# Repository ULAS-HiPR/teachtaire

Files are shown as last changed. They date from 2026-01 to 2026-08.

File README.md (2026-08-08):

# Teachtaire

Teachtaire is the telemetry and navigation node in [Ogma](https://sean-osullivan.com/projects/ogma/), the University of Limerick Aeronautics Society's modular avionics stack for high-powered rocketry.

## Role

- Relays stack telemetry over an SX1272 LoRa radio.
- Reads position and timing from a u-blox MAX-M10S GNSS receiver.
- Exchanges telemetry and status over the 500 kbit/s CAN bus.
- Runs on an STM32F072.

## Repository

- `hardware/` - KiCad design and manufacturing outputs.
- `firmware/` - embedded firmware, radio/GNSS probes, and tests.

## Status

Rev 1 firmware and hardware bring-up continue on [`ogma/flight-hardening`](https://github.com/ULAS-HiPR/teachtaire/tree/ogma/flight-hardening). Release-candidate firmware builds and software tests pass, but hardware-in-the-loop validation is still underway. Teachtaire is not yet flight-proven.

## Manufacturing support

Rev 1 PCB fabrication was sponsored through [EasyEDA Education](https://easyeda.com/education) and manufactured by [JLCPCB](https://jlcpcb.com/). The board was designed in KiCad and imported into EasyEDA Pro for the sponsorship and manufacturing workflow.

## More information

See the [Ogma project write-up](https://sean-osullivan.com/projects/ogma/) for the complete stack, bring-up work, and current status.

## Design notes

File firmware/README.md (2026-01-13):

# Teachtaire

Teachtaire is the primary comms board. It has LoRa radio and gnss for finding the rocket during/after launch.

# Set-Up

```bash
git clone git@github.com:ULAS-HiPR/teachtaire.git
cd teachtaire
git submodule update --init --recursive
```

# Libraries used:

## From Braiteoiri:

- Radio: SX1261
- GNSS
- LED

## From Comheadan:

- CAN
- SPI
- UART

## Other:

- FreeRTOS

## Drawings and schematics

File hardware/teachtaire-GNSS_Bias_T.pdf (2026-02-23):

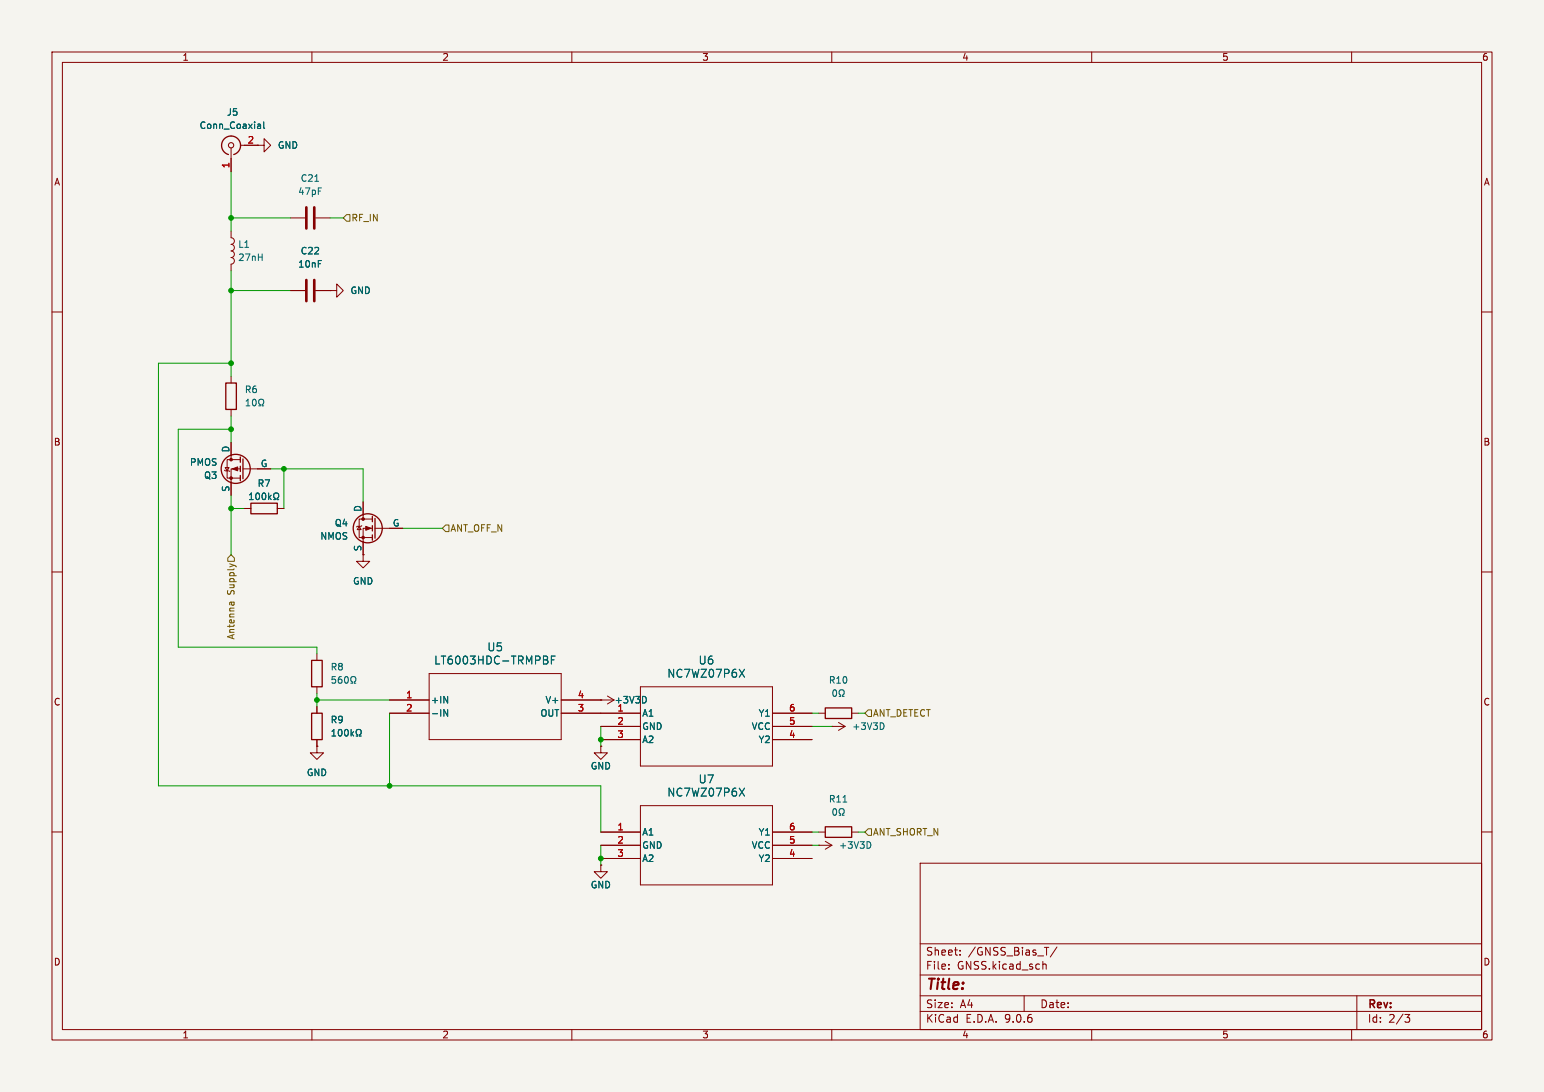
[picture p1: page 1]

Id: 2/3 Title: File: GNSS.kicad_sch Sheet: /GNSS_Bias_T/ R11

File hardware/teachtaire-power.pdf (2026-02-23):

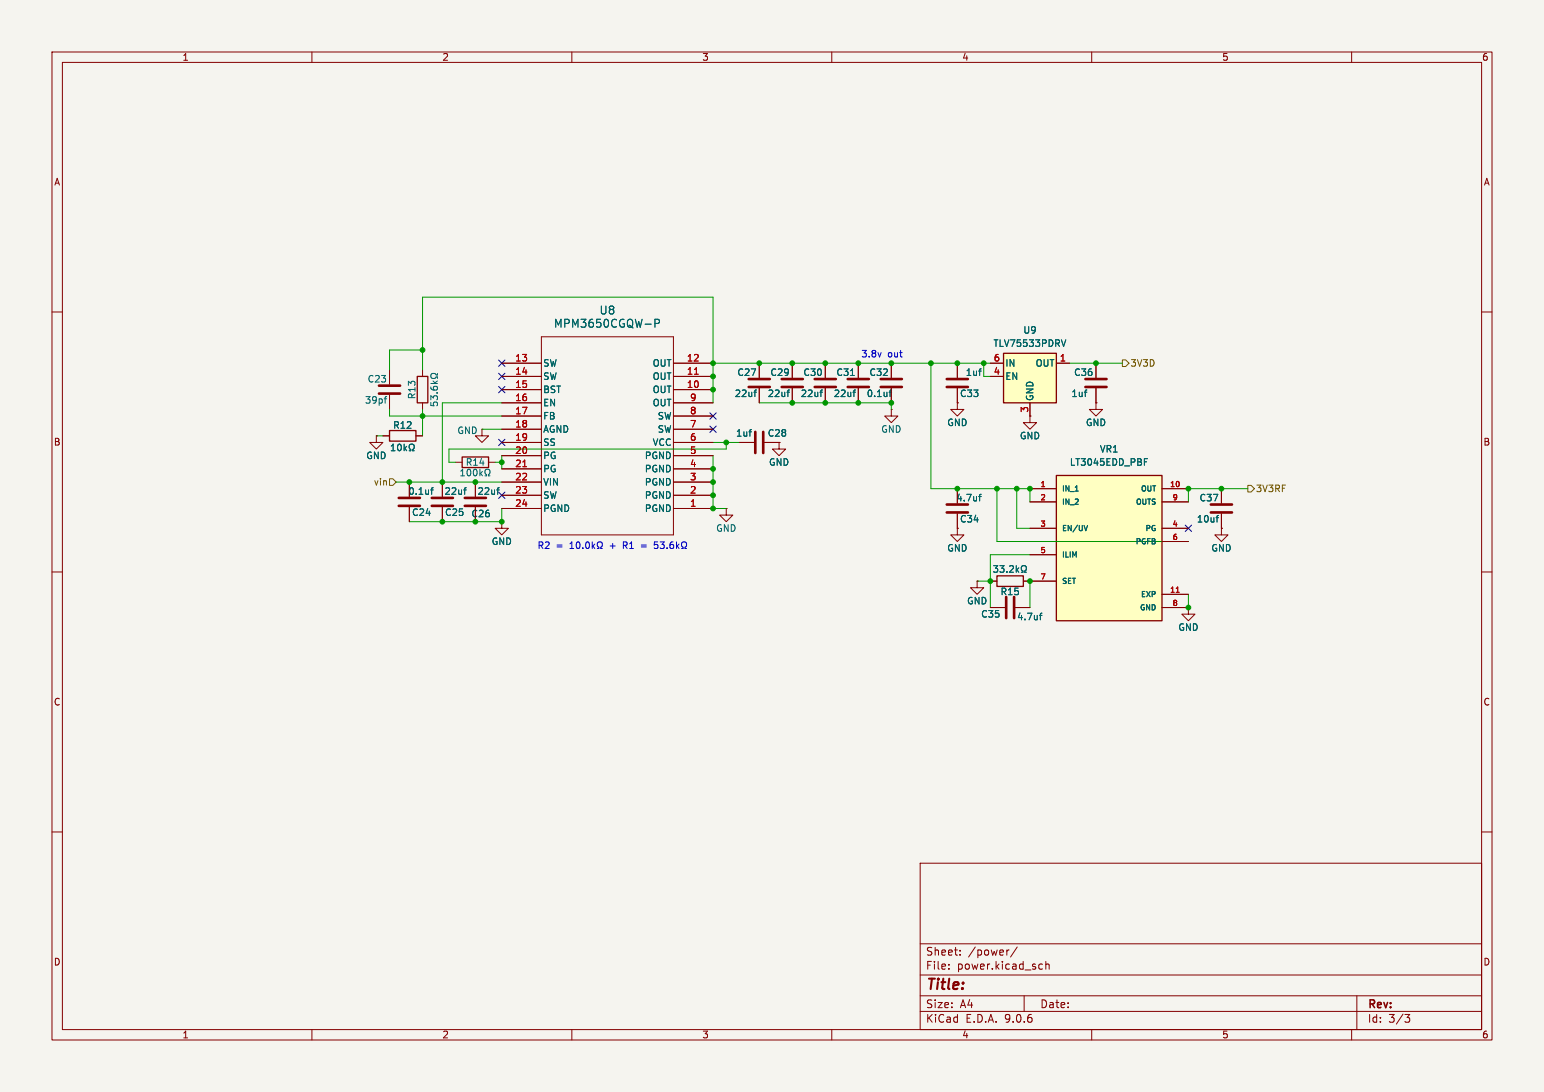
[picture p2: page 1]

Id: 3/3 Title: File: power.kicad_sch Sheet: /power/

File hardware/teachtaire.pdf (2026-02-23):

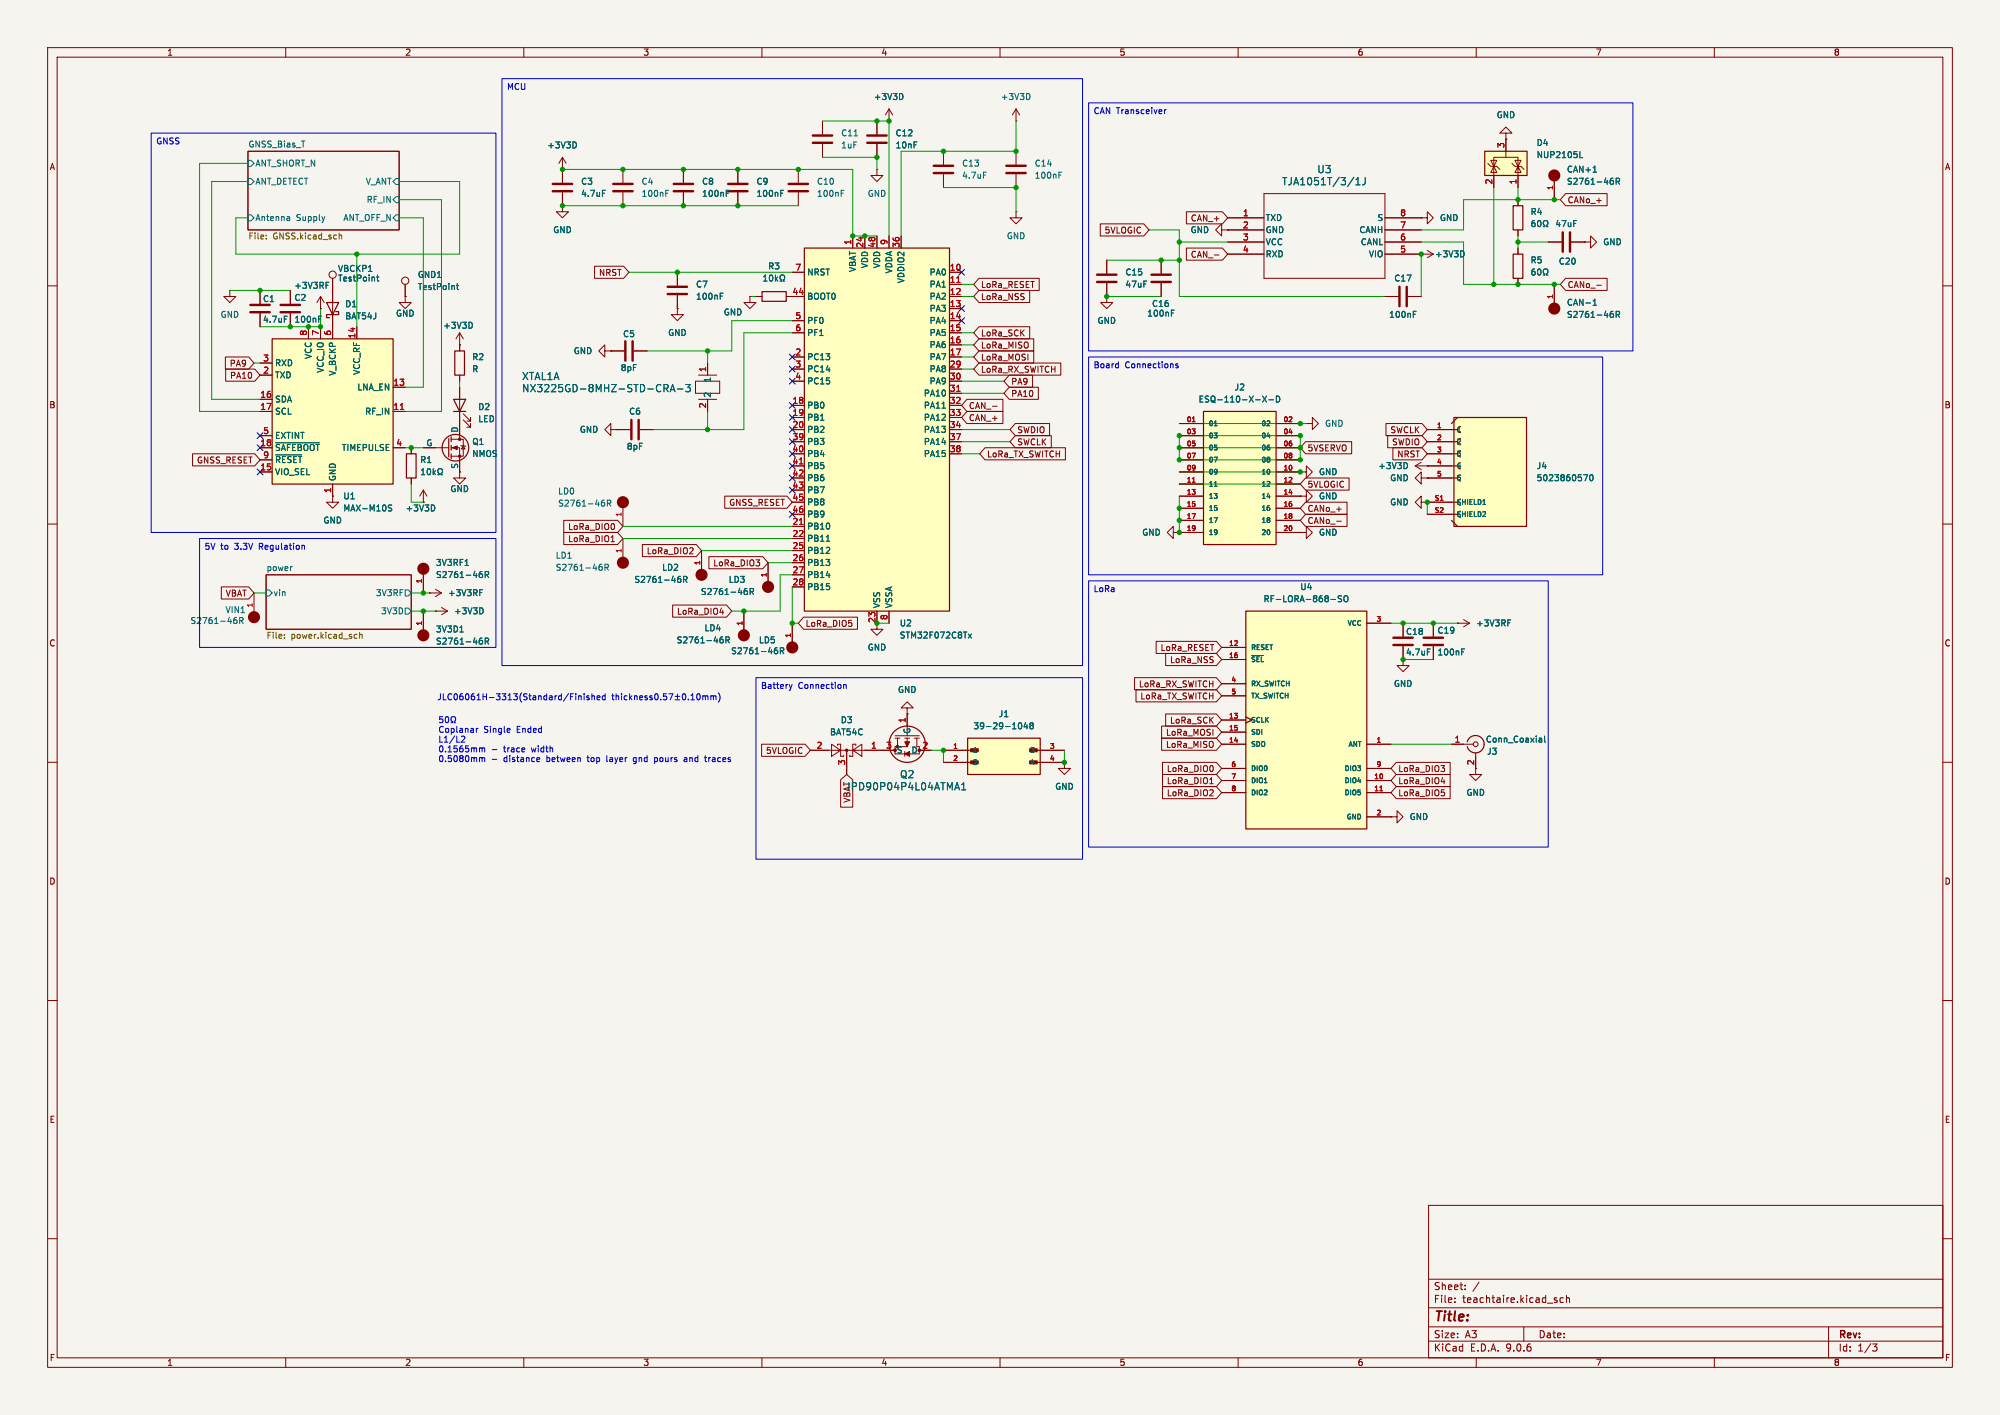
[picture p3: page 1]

1 VDD 24 VDD 48 VSS 23 VDDA

1 GND GND XTAL1A NX3225GD-8MHZ-STD-CRA-3

Id: 1/3 Title: File: teachtaire.kicad_sch Sheet: /

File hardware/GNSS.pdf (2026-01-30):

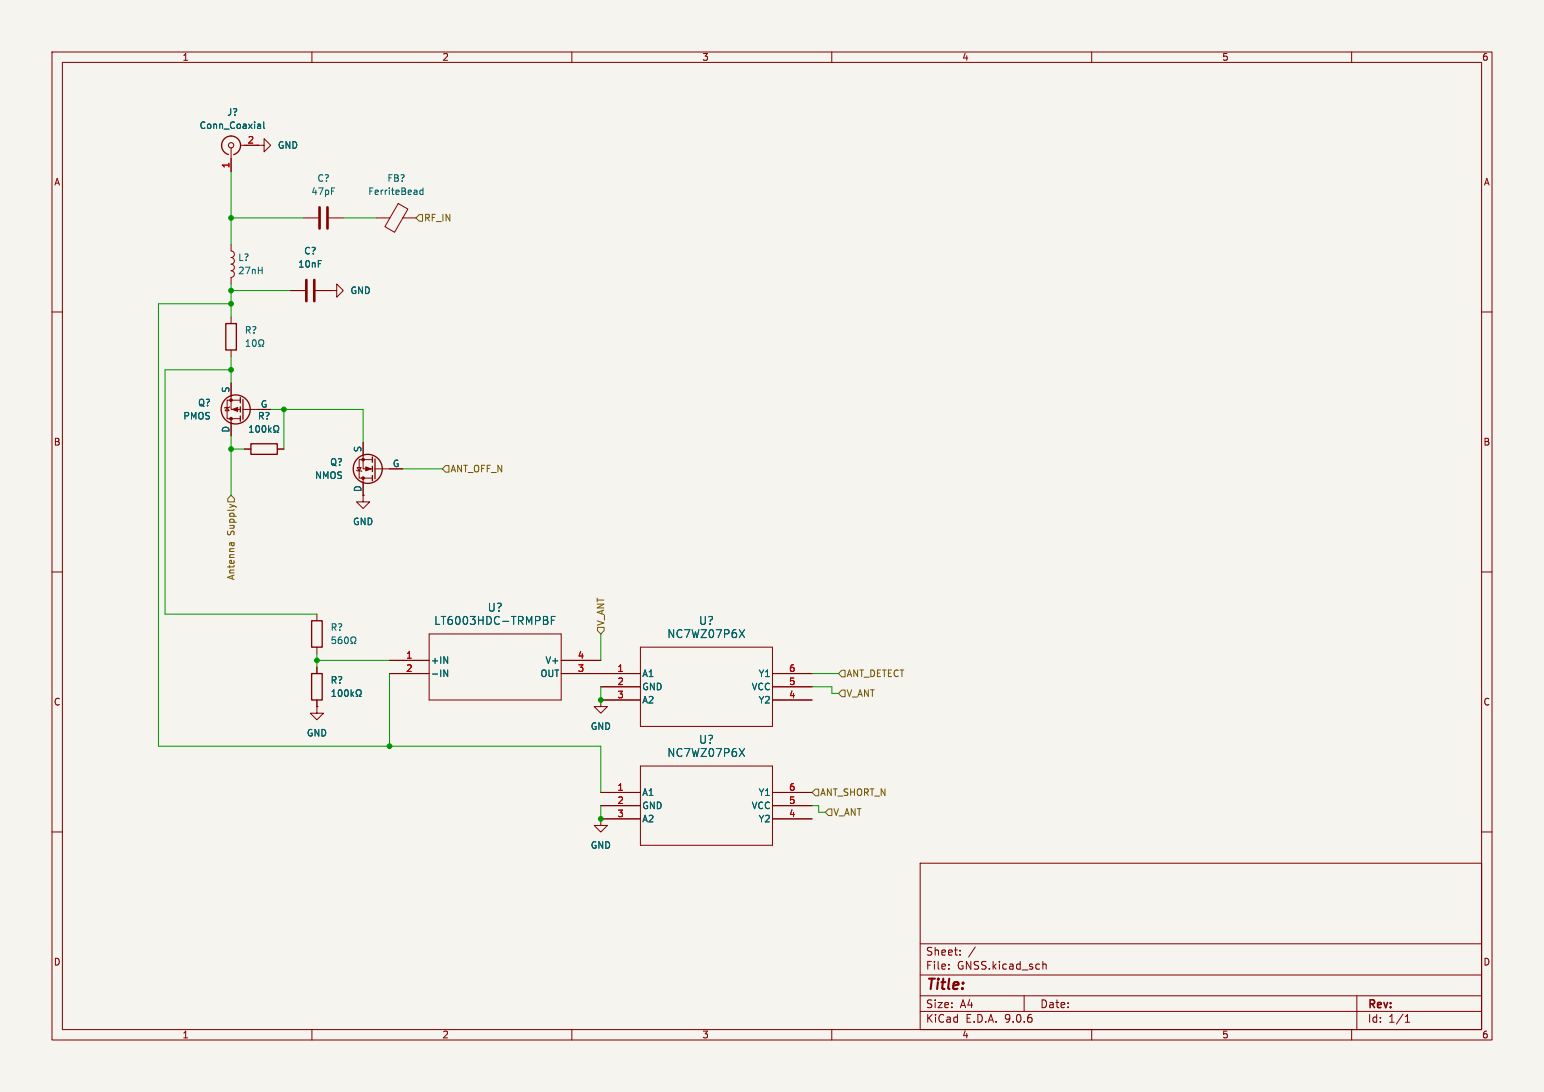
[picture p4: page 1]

Id: 1/1 Title: File: GNSS.kicad_sch Sheet: /

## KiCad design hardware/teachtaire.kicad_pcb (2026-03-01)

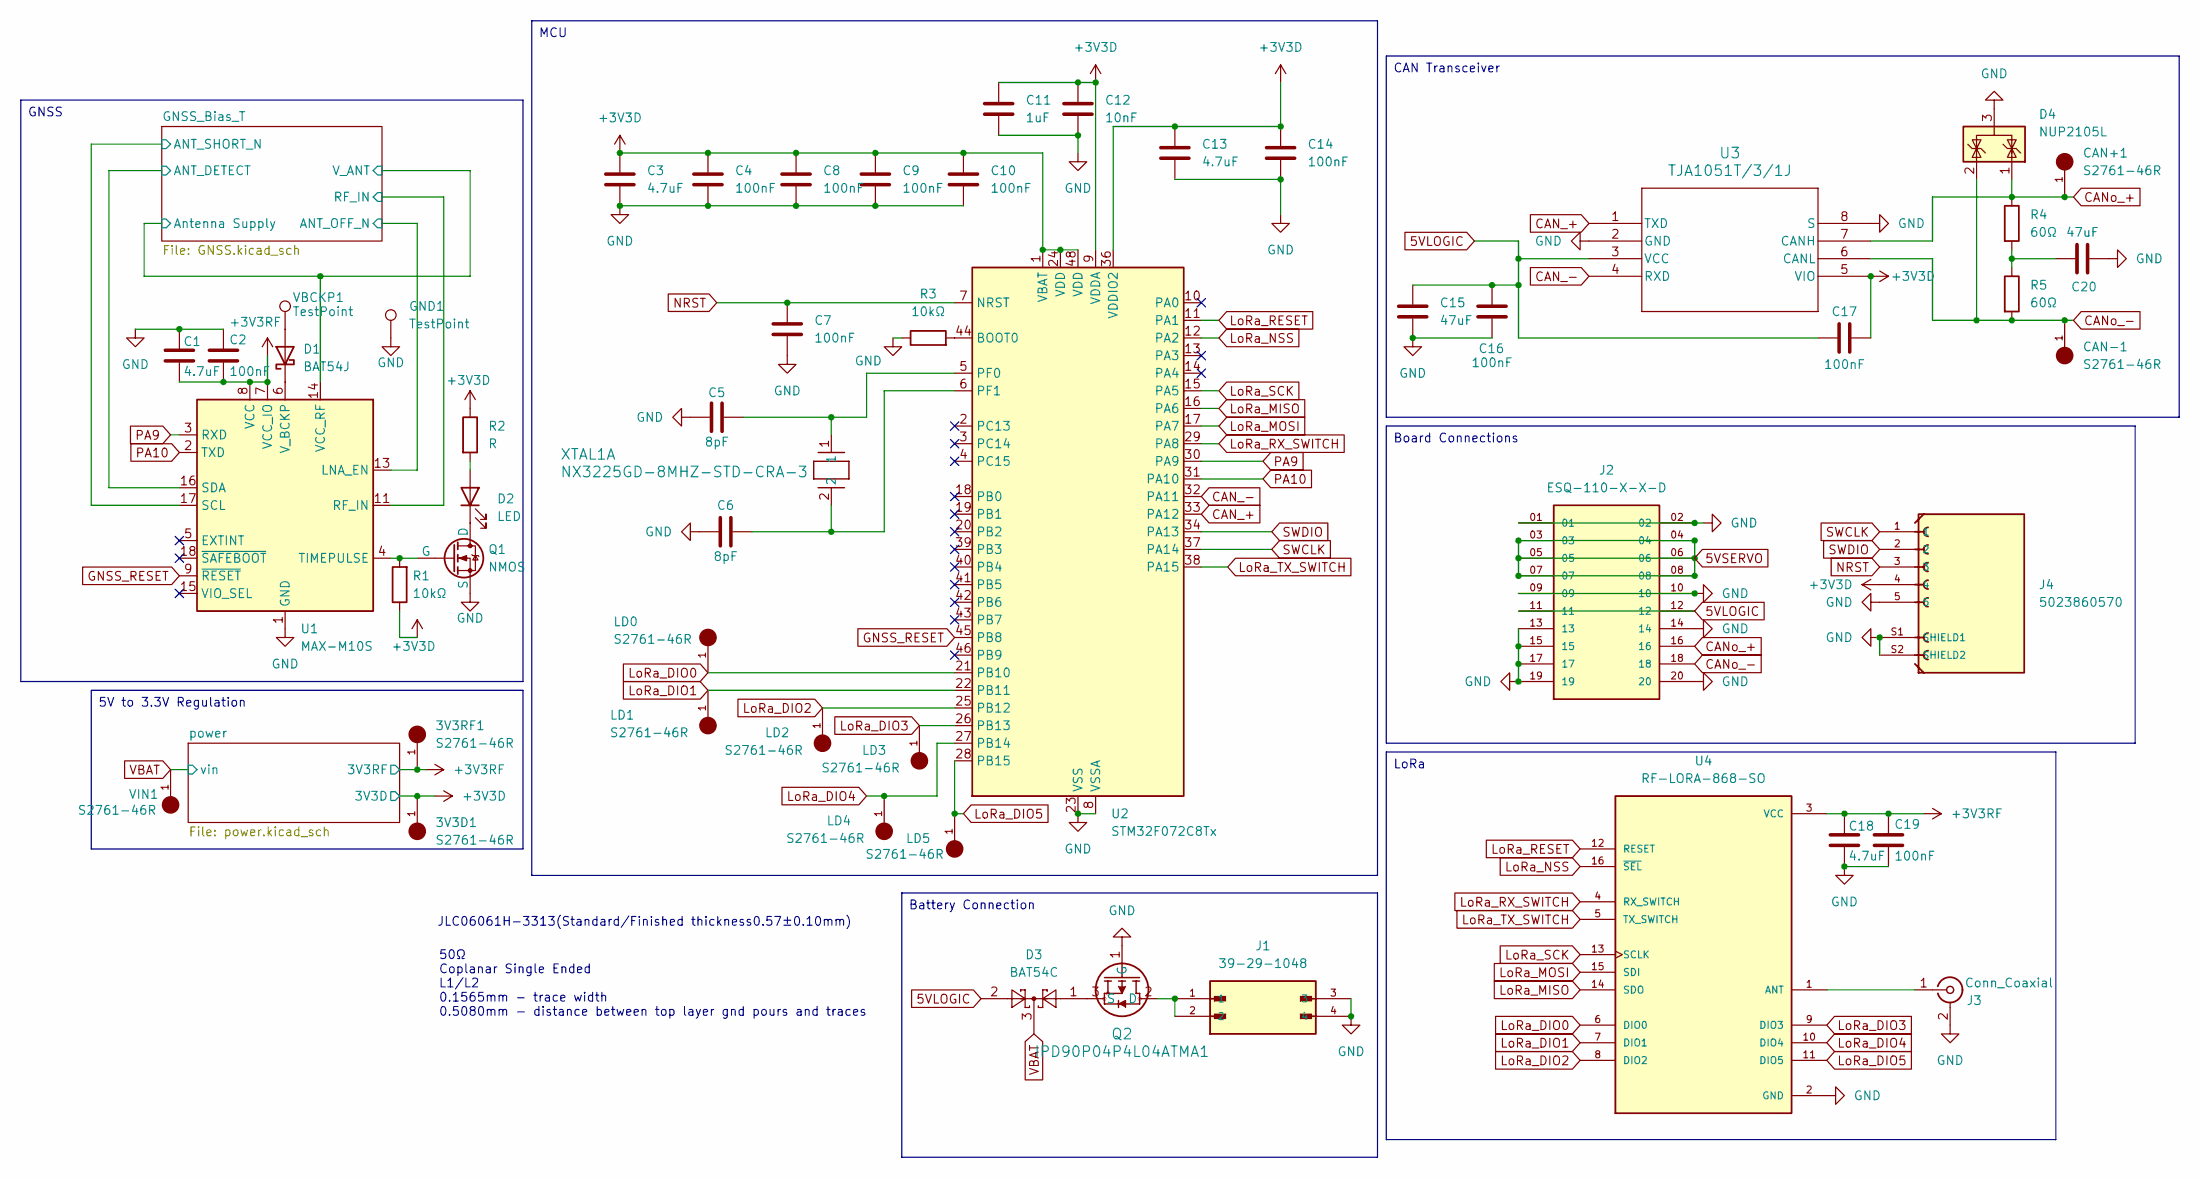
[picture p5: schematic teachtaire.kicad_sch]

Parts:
3V3D1, 3V3RF1: S2761-46R; HARWIN_S2761-46R; PARTREV 1
C1, C3, C13, C18: 4.7uF; C_0402_1005Metric
C2, C4, C7, C8, C9, C10, C14, C16, C17, C19: 100nF; C_0402_1005Metric
C5, C6: 8pF; C_0402_1005Metric
C11: 1uF; C_0402_1005Metric
C12: 10nF; C_0402_1005Metric
C15, C20: 47uF; C_0402_1005Metric
CAN+1: S2761-46R; HARWIN_S2761-46R; PARTREV 1
CAN-1: S2761-46R; HARWIN_S2761-46R; PARTREV 1
D1: BAT54J; D_SOD-323F
D2: LED; LED_0402_1005Metric
D3: BAT54C; SOT-23
D4: NUP2105L; SOT-23
GND1: TestPoint; TestPoint_Pad_D2.0mm
J1: 39-29-1048; MOLEX_39-29-1048
J2: ESQ-110-X-X-D; SAMTEC_ESQ-110-14-G-D; PARTREV NA
J3: Conn_Coaxial; SMA_BAT_Wireless_BWSMA-KWE-Z001
J4: 5023860570; MOLEX_5023860570; PARTREV F
LD0, LD1, LD2, LD3, LD4, LD5: S2761-46R; HARWIN_S2761-46R; PARTREV 1
Q1: NMOS; SOT-23
Q2: IPD90P04P4L04ATMA1; PG-TO252-3-313_INF-L
R1, R3: 10kΩ; R_0402_1005Metric
R2: R; R_0402_1005Metric
R4, R5: 60Ω; R_0402_1005Metric
U1: MAX-M10S; ublox_MAX
U2: STM32F072C8Tx; LQFP-48_7x7mm_P0.5mm
U3: TJA1051T/3/1J; SO8_SOT96-1_NXP
U4: RF-LORA-868-SO; XCVR_RF-LORA-868-SO
VBCKP1: TestPoint; TestPoint_Pad_D2.0mm
VIN1: S2761-46R; HARWIN_S2761-46R; PARTREV 1
XTAL1: NX3225GD-8MHZ-STD-CRA-3; XTAL_NX3225GD-8MHZ-STD-CRA-3_NDK

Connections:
5VLOGIC: C15.1, C16.1, C17.1, D3.2, J2.11, J2.12, U3.3 (VCC)
5VSERVO: J2.03, J2.04, J2.05, J2.06, J2.07, J2.08
+3V3D: 3V3D1.1, C3.1, C4.1, C8.1, C9.1, C10.1, C11.1, C12.1, C13.1, C14.1, C17.2, J4.4, R1.1, R2.1, U2.1 (VBAT), U2.9 (VDDA), U2.24 (VDD), U2.36 (VDDIO2), U2.48 (VDD), U3.5 (VIO); also elsewhere on the board
+3V3RF: 3V3RF1.1, C1.2, C2.2, C18.1, C19.1, U1.7 (VCC_IO), U1.8 (VCC), U4.3 (VCC); also elsewhere on the board
/GNSS_Bias_T/ANT_DETECT: U1.16 (SDA); also elsewhere on the board
/GNSS_Bias_T/ANT_OFF_N: U1.13 (LNA_EN); also elsewhere on the board
/GNSS_Bias_T/ANT_SHORT_N: U1.17 (SCL); also elsewhere on the board
/GNSS_Bias_T/Antenna Supply: U1.14 (VCC_RF); also elsewhere on the board
/GNSS_Bias_T/RF_IN: U1.11 (RF_IN); also elsewhere on the board
CAN_+: U2.33 (PA12), U3.1 (TXD)
CAN_-: U2.32 (PA11), U3.4 (RXD)
CANo_+: CAN+1.1, D4.1 (K), J2.16, R4.1, U3.7 (CANH)
CANo_-: CAN-1.1, D4.2 (K), J2.18, R5.2, U3.6 (CANL)
GND: C1.1, C2.1, C3.2, C4.2, C5.1, C6.1, C7.2, C8.2, C9.2, C10.2, C11.2, C12.2, C13.2, C14.2, C15.2, C16.2, C18.2, C19.2, C20.2, D4.3 (A), GND1.1, J1.3, J1.4, J2.01, J2.02, J2.09, J2.10, J2.13, J2.14, J2.15, J2.17, J2.19, J2.20, J3.2 (Ext), J4.5, J4.S1 (SHIELD1), J4.S2 (SHIELD2), Q1.3 (S), Q2.1 (G), R3.1, U1.1 (GND), U1.10 (GND), U1.12 (GND), U2.8 (VSSA), U2.23 (VSS), U2.35 (VSS), U2.47 (VSS), U3.2 (GND), U3.8 (S), U4.2 (GND); also elsewhere on the board
GNSS_RESET: U1.9 (~RESET), U2.45 (PB8)
LoRa_DIO0: LD0.1, U2.21 (PB10), U4.6 (DIO0)
LoRa_DIO1: LD1.1, U2.22 (PB11), U4.7 (DIO1)
LoRa_DIO2: LD2.1, U2.25 (PB12), U4.8 (DIO2)
LoRa_DIO3: LD3.1, U2.26 (PB13), U4.9 (DIO3)
LoRa_DIO4: LD4.1, U2.27 (PB14), U4.10 (DIO4)
LoRa_DIO5: LD5.1, U2.28 (PB15), U4.11 (DIO5)
LoRa_MISO: U2.16 (PA6), U4.14 (SDO)
LoRa_MOSI: U2.17 (PA7), U4.15 (SDI)
LoRa_NSS: U2.12 (PA2), U4.16 (~SEL)
LoRa_RESET: U2.11 (PA1), U4.12 (RESET)
LoRa_RX_SWITCH: U2.29 (PA8), U4.4 (RX_SWITCH)
LoRa_SCK: U2.15 (PA5), U4.13 (SCLK)
LoRa_TX_SWITCH: U2.38 (PA15), U4.5 (TX_SWITCH)
NRST: C7.1, J4.3, U2.7 (NRST)
unnamed: C20.1, R4.2, R5.1
unnamed: D1.2 (A), VBCKP1.1
unnamed: D1.1 (K), U1.6 (V_BCKP)
unnamed: D2.2 (A), R2.2
unnamed: D2.1 (K), Q1.1 (D)
unnamed: J3.1 (In), U4.1 (ANT)
unnamed: Q1.2 (G), R1.2, U1.4 (TIMEPULSE)
unnamed: J1.1, J1.2, Q2.2 (D)
unnamed: D3.1, Q2.3 (S)
unnamed: R3.2, U2.44 (BOOT0)
unnamed: C5.2, U2.5 (PF0), XTAL1.1
unnamed: C6.2, U2.6 (PF1), XTAL1.2
PA9: U1.3 (RXD), U2.30 (PA9)
PA10: U1.2 (TXD), U2.31 (PA10)
SWCLK: J4.1, U2.37 (PA14)
SWDIO: J4.2, U2.34 (PA13)
VBAT: D3.3, VIN1.1; also elsewhere on the board

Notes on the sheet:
50Ω Coplanar Single Ended L1/L2 0.1565mm - trace width 0.5080mm - distance between top layer gnd pours and traces
JLC06061H-3313(Standard/Finished thickness0.57±0.10mm)
Board Connections
Battery Connection
LoRa
CAN Transceiver
GNSS
MCU
5V to 3.3V Regulation

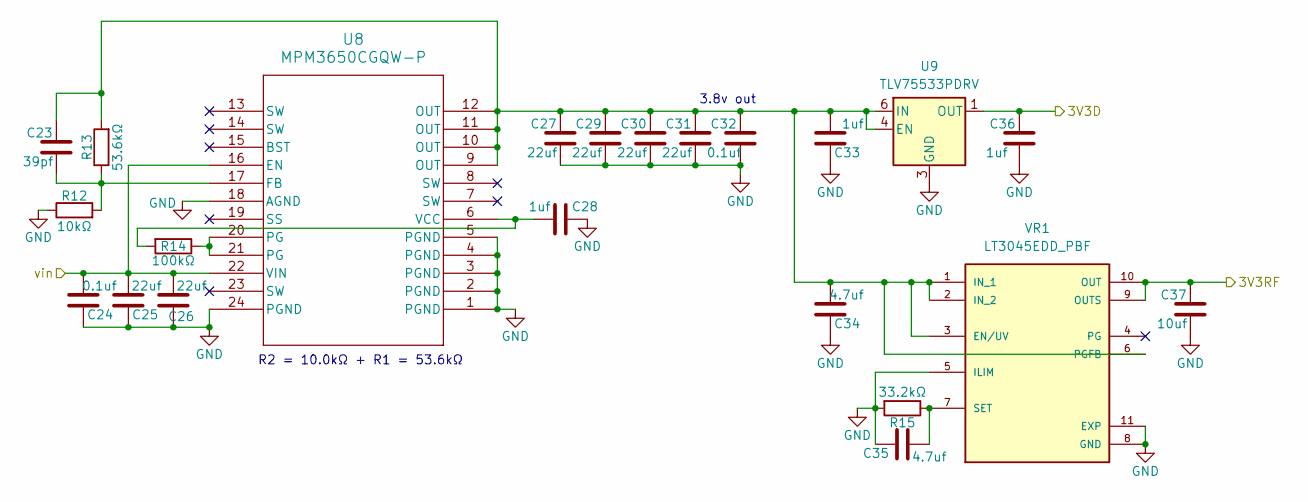
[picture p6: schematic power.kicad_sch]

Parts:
C23: 39pf; C_0402_1005Metric
C24, C32: 0.1uf; C_0402_1005Metric
C25, C26, C27, C29, C30, C31: 22uf; C_0402_1005Metric
C28, C33, C36: 1uf; C_0402_1005Metric
C34, C35: 4.7uf; C_0402_1005Metric
C37: 10uf; C_0402_1005Metric
R12: 10kΩ; R_0402_1005Metric
R13: 53.6kΩ; R_0402_1005Metric
R14: 100kΩ; R_0402_1005Metric
R15: 33.2kΩ; R_0402_1005Metric
U8: MPM3650CGQW-P; QFN-24_MPM3650_MNP
U9: TLV75533PDRV; WSON-6-1EP_2x2mm_P0.65mm_EP1x1.6mm
VR1: LT3045EDD_PBF; SON50P300X300X80-11N; PARTREV C

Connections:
+3V3D: C36.1, U9.1 (OUT); also elsewhere on the board
+3V3RF: C37.1, VR1.9 (OUTS), VR1.10 (OUT); also elsewhere on the board
GND: C24.1, C25.1, C26.1, C27.2, C28.1, C29.2, C30.2, C31.2, C32.2, C33.1, C34.1, C35.1, C36.2, C37.2, R12.1, R15.2, U8.1 (PGND), U8.2 (PGND), U8.3 (PGND), U8.4 (PGND), U8.5 (PGND), U8.18 (AGND), U8.24 (PGND), U9.3 (GND), U9.7 (GND), VR1.5 (ILIM), VR1.8 (GND), VR1.11 (EXP); also elsewhere on the board
unnamed: R14.1, U8.20 (PG), U8.21 (PG)
unnamed: C23.2, R12.2, R13.1, U8.17 (FB)
unnamed: C28.2, R14.2, U8.6 (VCC)
unnamed: C23.1, C27.1, C29.1, C30.1, C31.1, C32.1, C33.2, C34.2, R13.2, U8.9 (OUT), U8.10 (OUT), U8.11 (OUT), U8.12 (OUT), U9.4 (EN), U9.6 (IN), VR1.1 (IN_1), VR1.2 (IN_2), VR1.3 (EN/UV), VR1.6 (PGFB)
unnamed: C35.2, R15.1, VR1.7 (SET)
VBAT: C24.2, C25.2, C26.2, U8.16 (EN), U8.22 (VIN); also elsewhere on the board

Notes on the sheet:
3.8v out
R2 = 10.0kΩ + R1 = 53.6kΩ

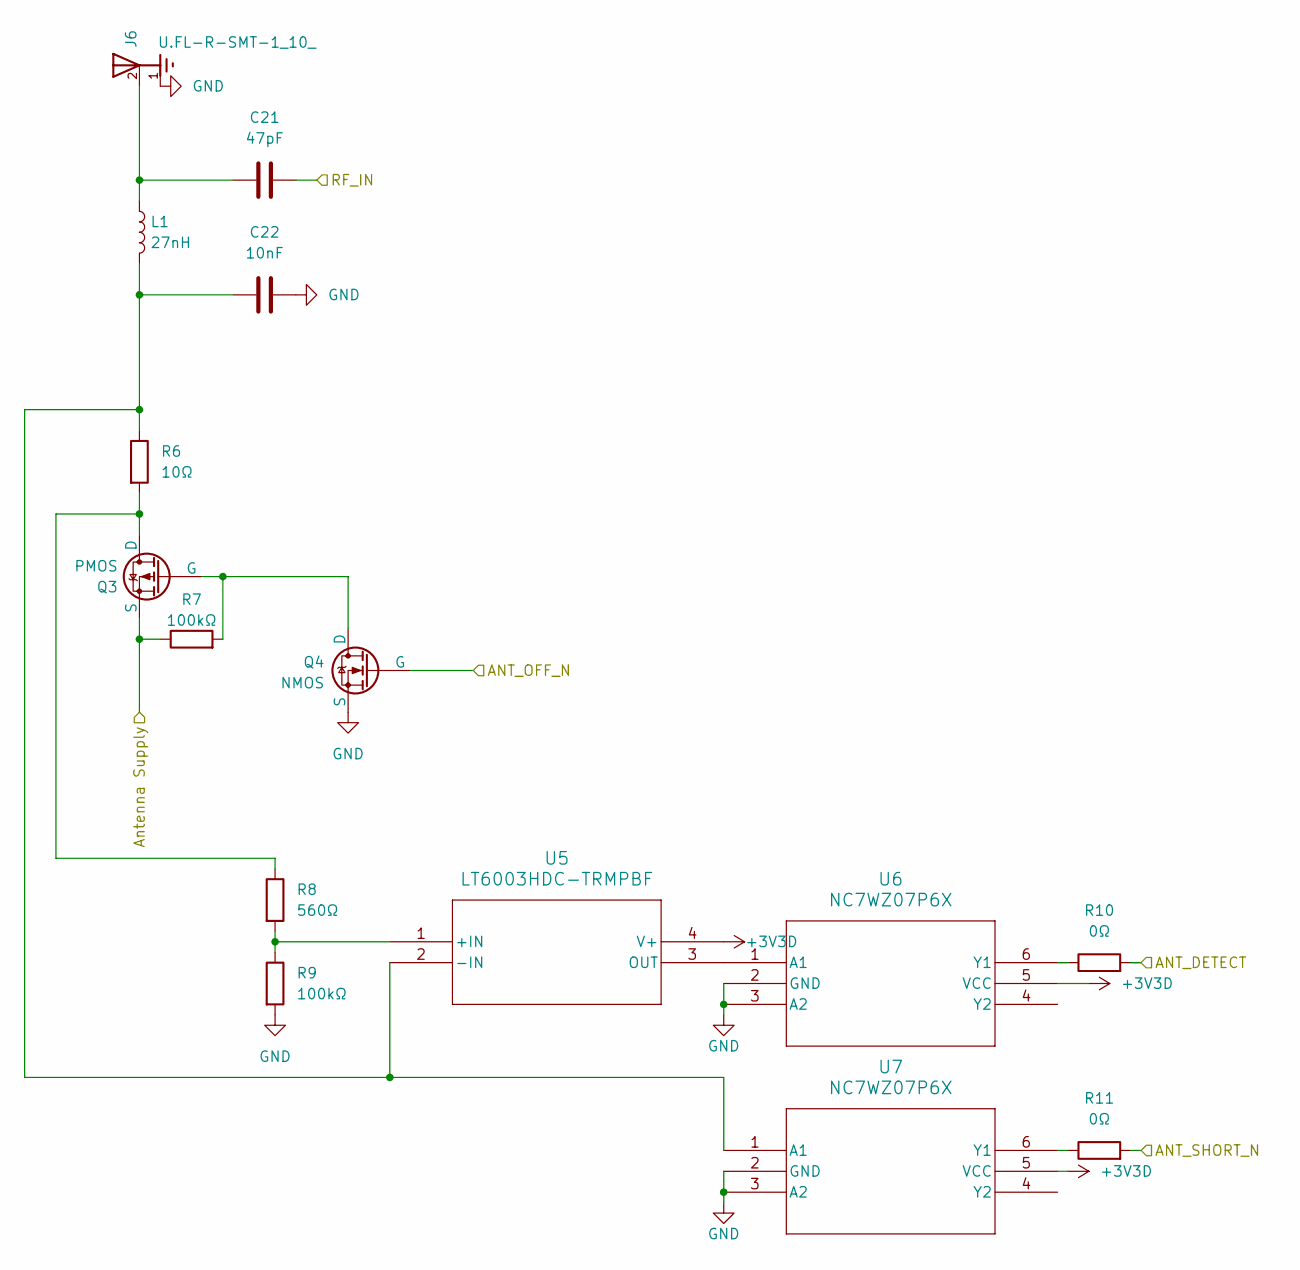
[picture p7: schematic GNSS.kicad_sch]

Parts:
C21: 47pF; C_0402_1005Metric
C22: 10nF; C_0402_1005Metric
J6: U.FL-R-SMT-1_10_; HRS_U.FL-R-SMT-1_10_
L1: 27nH; L_0402_1005Metric
Q3: PMOS; SOT-23
Q4: NMOS; SOT-23
R6: 10Ω; R_0402_1005Metric
R7, R9: 100kΩ; R_0402_1005Metric
R8: 560Ω; R_0402_1005Metric
R10, R11: 0Ω; R_0402_1005Metric
U5: LT6003HDC-TRMPBF; DC_4_ADI
U6, U7: NC7WZ07P6X; SC-88&slash_SC70-6&slash_SOT-363_419B-02_ONS

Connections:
+3V3D: U5.4 (V+), U6.5 (VCC), U7.5 (VCC); also elsewhere on the board
/GNSS_Bias_T/ANT_DETECT: R10.2; also elsewhere on the board
/GNSS_Bias_T/ANT_OFF_N: Q4.2 (G); also elsewhere on the board
/GNSS_Bias_T/ANT_SHORT_N: R11.2; also elsewhere on the board
/GNSS_Bias_T/Antenna Supply: Q3.3 (S), R7.1; also elsewhere on the board
/GNSS_Bias_T/RF_IN: C21.2; also elsewhere on the board
GND: C22.2, J6.1, J6.3, Q4.3 (S), R9.2, U6.2 (GND), U6.3 (A2), U7.2 (GND), U7.3 (A2); also elsewhere on the board
unnamed: C21.1, J6.2, L1.1
unnamed: Q3.1 (D), R6.2, R8.1
unnamed: Q3.2 (G), Q4.1 (D), R7.2
unnamed: R8.2, R9.1, U5.1 (+IN)
unnamed: C22.1, L1.2, R6.1, U5.2 (-IN), U7.1 (A1)
unnamed: U5.3 (OUT), U6.1 (A1)
unnamed: R10.1, U6.6 (Y1)
unnamed: R11.1, U7.6 (Y1)

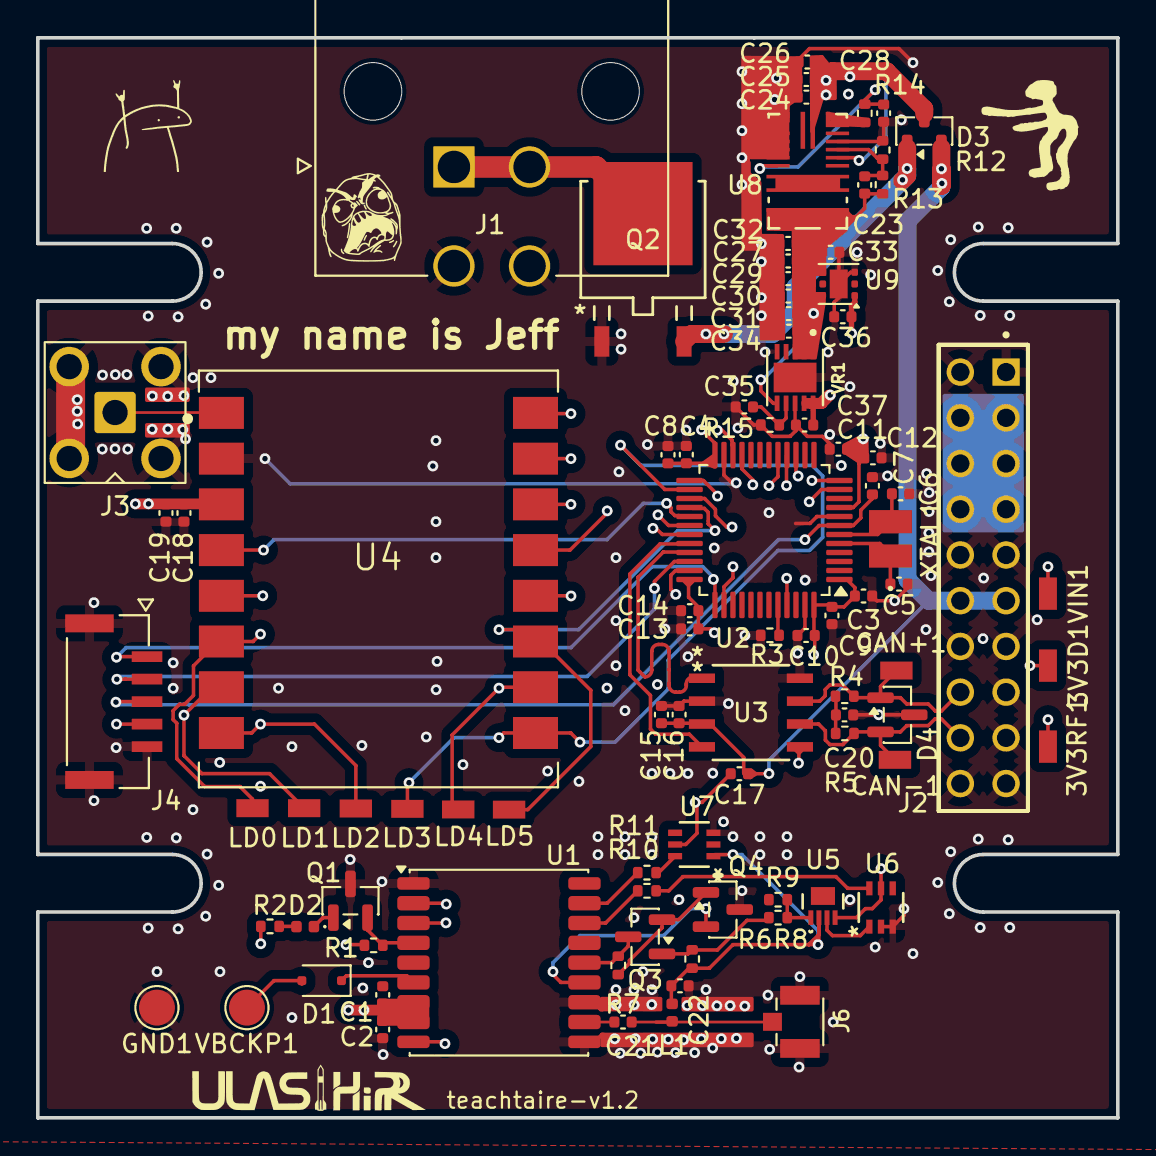
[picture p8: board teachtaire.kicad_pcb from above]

Board: 6 copper layers, 60.0 x 60.0 mm, 90 parts (0 on the bottom side), 59 nets.

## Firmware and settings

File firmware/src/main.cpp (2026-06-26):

#if F4
#include "stm32f4xx_hal.h"
#include "platform/stm_f4.h"
#endif
#if F0
#include "stm32f0xx_hal.h"
#include "platform/stm_f0.h"
#endif
#include "cmsis_os.h"
#include "FreeRTOS.h"
#include "task.h"
#include "platform/error_handler.h"
#include "platform/hal_time.h"

//generics
#include <data.h>
#include <sensor.h>

#include <SPI/SPI_Handler.h>
#include <UART/UART_Handler.h>
#include <CAN/CAN_Handler.h>

#include <Radio/Radio.h>
#include <GNSS/GNSS.h>

//specifics
#include <SPI/SPI_STM.h>
#include <UART/UART_STM.h>
#if F4
#include <CAN/CAN_Mock.h>
#elif F0
#include <CAN/CAN_STM.h>
#endif

#include <Radio/SX1272.h>
#include <GNSS/MAXM10S.h>

//tasks
#include "tasks/CAN_task.h"
#include "tasks/telem_task.h"

#define SYNC_WORD 0x4F // O for Ogma, P for Payload


void SystemClock_Config(void);


const osMessageQueueAttr_t canRQueue_attributes = {
  .name = "canReciverQueue"
};

const osMessageQueueAttr_t canSQueue_attributes = {
  .name = "canSenderQueue"
};

int main(void)
{
  HAL_Init();
  SystemClock_Config();
  osKernelInitialize();

  MX_GPIO_Init();
  MX_SPI1_Init();
  MX_USART1_UART_Init();

  
  SPI_Handler* spi_handler_radio = new SPI_STM(&hspi1, RADIO_CS_PORT, RADIO_CS_PIN);
  UART_Handler* uart_handler_gnss = new UART_STM(&huart1);

  //only for testing
  sx1272_pins_t radio_pins = {
      .reset_write = [](bool high, void* context) {
          GPIO_TypeDef* port = static_cast<GPIO_TypeDef*>(context);
          HAL_GPIO_WritePin(port, RADIO_RESET_PIN, high ? GPIO_PIN_SET : GPIO_PIN_RESET);
      },
      .reset_context = RADIO_RESET_PORT,
      .delay_ms = [](std::uint32_t ms, void* context) {
          HAL_Delay(ms);
      },
      .delay_context = nullptr,
      .switch_write = [](sx1272_switch_mode_t mode, void* context) {
          switch (mode) {
              case sx1272_switch_mode_t::OFF:
                  HAL_GPIO_WritePin(RADIO_RX_SW_PORT, RADIO_RX_SW_PIN, GPIO_PIN_RESET);
                  HAL_GPIO_WritePin(RADIO_TX_SW_PORT, RADIO_TX_SW_PIN, GPIO_PIN_RESET);
                  break;
              case sx1272_switch_mode_t::RX:
                  HAL_GPIO_WritePin(RADIO_RX_SW_PORT, RADIO_RX_SW_PIN, GPIO_PIN_SET);
                  HAL_GPIO_WritePin(RADIO_TX_SW_PORT, RADIO_TX_SW_PIN, GPIO_PIN_RESET);
                  break;
              case sx1272_switch_mode_t::TX:
                  HAL_GPIO_WritePin(RADIO_RX_SW_PORT, RADIO_RX_SW_PIN, GPIO_PIN_RESET);
                  HAL_GPIO_WritePin(RADIO_TX_SW_PORT, RADIO_TX_SW_PIN, GPIO_PIN_SET);
                  break;
          }
      },
      .switch_context = nullptr
  };

  Radio* radio = new SX1272(*spi_handler_radio, RADIO_CS_PIN, radio_pins, SYNC_WORD);
  GNSS* gnss = new MAXM10S(*uart_handler_gnss);
  bool init_status_radio = radio->init();
  bool init_status_gnss = gnss->init();


  #if F4
    static CAN_MOCK canbus;
  #elif F0
    MX_CAN_Init();
    static CAN_STM canbus(&hcan);
    if (!canbus.init()) {
       Error_Handler();
    }
  #endif

  osMessageQueueId_t canReciverQueueHandle = osMessageQueueNew(4, sizeof(flight_data), &canRQueue_attributes);
  osMessageQueueId_t canSenderQueueHandle = osMessageQueueNew(4, sizeof(gps_data), &canSQueue_attributes);

  static task::Telem_Task telem_task(*radio, *gnss, canReciverQueueHandle, canSenderQueueHandle);
  static task::CAN_task can_task(canbus, canSenderQueueHandle, canReciverQueueHandle, NODE_TEACHTAIRE);

  telem_task.run();
  can_task.run();

  
  osKernelStart();
  // never get here 
  while (1)
  {
    HAL_Delay(1000);
  }
}



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


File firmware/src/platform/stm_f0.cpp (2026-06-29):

#if F0
#include "stm_f0.h"


CAN_HandleTypeDef hcan;
SPI_HandleTypeDef hspi1;
UART_HandleTypeDef huart1;

void HAL_MspInit(void)
{

  __HAL_RCC_SYSCFG_CLK_ENABLE();
  __HAL_RCC_PWR_CLK_ENABLE();

  /* System interrupt init*/
  /* PendSV_IRQn interrupt configuration */
  HAL_NVIC_SetPriority(PendSV_IRQn, 3, 0);

}



/**
  * @brief CAN Initialization Function
  * @param None
  * @retval None
  */
void MX_CAN_Init(void)
{

  hcan.Instance = CAN;
  hcan.Init.Prescaler = 6;
  //hcan.Init.Mode = CAN_MODE_LOOPBACK;
  hcan.Init.Mode = CAN_MODE_NORMAL;
  hcan.Init.SyncJumpWidth = CAN_SJW_1TQ;
  hcan.Init.TimeSeg1 = CAN_BS1_13TQ;
  hcan.Init.TimeSeg2 = CAN_BS2_2TQ;
  hcan.Init.TimeTriggeredMode = DISABLE;
  hcan.Init.AutoBusOff = DISABLE;
  hcan.Init.AutoWakeUp = DISABLE;
  hcan.Init.AutoRetransmission = ENABLE;
  hcan.Init.ReceiveFifoLocked = DISABLE;
  hcan.Init.TransmitFifoPriority = DISABLE;
  if (HAL_CAN_Init(&hcan) != HAL_OK)
  {
    Error_Handler();
  }
}


/**
  * @brief CAN MSP Initialization
  * This function configures the hardware resources used in this example
  * @param hcan: CAN handle pointer
  * @retval None
  */
void HAL_CAN_MspInit(CAN_HandleTypeDef* hcan)
{
  GPIO_InitTypeDef GPIO_InitStruct = {0};
  if(hcan->Instance==CAN)
  {
    /* Peripheral clock enable */
    __HAL_RCC_CAN1_CLK_ENABLE();

    __HAL_RCC_GPIOA_CLK_ENABLE();
    /**CAN GPIO Configuration
    PA11     ------> CAN_RX
    PA12     ------> CAN_TX
    */
    GPIO_InitStruct.Pin = GPIO_PIN_11|GPIO_PIN_12;
    GPIO_InitStruct.Mode = GPIO_MODE_AF_PP;
    GPIO_InitStruct.Pull = GPIO_NOPULL;
    GPIO_InitStruct.Speed = GPIO_SPEED_FREQ_HIGH;
    GPIO_InitStruct.Alternate = GPIO_AF4_CAN;
    HAL_GPIO_Init(GPIOA, &GPIO_InitStruct);

  }

}

/**
  * @brief CAN MSP De-Initialization
  * This function freeze the hardware resources used in this example
  * @param hcan: CAN handle pointer
  * @retval None
  */
void HAL_CAN_MspDeInit(CAN_HandleTypeDef* hcan)
{
  if(hcan->Instance==CAN)
  {
    /* Peripheral clock disable */
    __HAL_RCC_CAN1_CLK_DISABLE();

    /**CAN GPIO Configuration
    PA11     ------> CAN_RX
    PA12     ------> CAN_TX
    */
    HAL_GPIO_DeInit(GPIOA, GPIO_PIN_11|GPIO_PIN_12);

  }

}

void MX_USART1_UART_Init(void)
{

  huart1.Instance = USART1;
  huart1.Init.BaudRate = 9600U;
  huart1.Init.WordLength = UART_WORDLENGTH_8B;
  huart1.Init.StopBits = UART_STOPBITS_1;
  huart1.Init.Parity = UART_PARITY_NONE;
  huart1.Init.Mode = UART_MODE_TX_RX;
  huart1.Init.HwFlowCtl = UART_HWCONTROL_NONE;
  huart1.Init.OverSampling = UART_OVERSAMPLING_16;
  huart1.AdvancedInit.AdvFeatureInit = UART_ADVFEATURE_NO_INIT;
  if (HAL_UART_Init(&huart1) != HAL_OK)
  {
    Error_Handler();
  }
}

/**
  * @brief UART MSP Initialization
  * This function configures the hardware resources used in this example
  * @param huart: UART handle pointer
  * @retval None
  */
void HAL_UART_MspInit(UART_HandleTypeDef* huart)
{
  GPIO_InitTypeDef GPIO_InitStruct = {0};
  if(huart->Instance==USART1)
  {
    /* Peripheral clock enable */
    __HAL_RCC_USART1_CLK_ENABLE();

    __HAL_RCC_GPIOA_CLK_ENABLE();
    /**USART1 GPIO Configuration
    PA9     ------> USART1_TX
    PA10     ------> USART1_RX
    */
    GPIO_InitStruct.Pin = GNSS_UART_TX_PIN|GNSS_UART_RX_PIN;
    GPIO_InitStruct.Mode = GPIO_MODE_AF_PP;
    GPIO_InitStruct.Pull = GPIO_PULLUP;
    GPIO_InitStruct.Speed = GPIO_SPEED_FREQ_HIGH;
    GPIO_InitStruct.Alternate = GPIO_AF1_USART1;
    HAL_GPIO_Init(GPIOA, &GPIO_InitStruct);

  }

}

/**
  * @brief UART MSP De-Initialization
  * This function freeze the hardware resources used in this example
  * @param huart: UART handle pointer
  * @retval None
  */
void HAL_UART_MspDeInit(UART_HandleTypeDef* huart)
{
  if(huart->Instance==USART1)
  {
    /* Peripheral clock disable */
    __HAL_RCC_USART1_CLK_DISABLE();

    /**USART1 GPIO Configuration
    PA9     ------> USART1_TX
    PA10     ------> USART1_RX
    */
    HAL_GPIO_DeInit(GPIOA, GNSS_UART_TX_PIN|GNSS_UART_RX_PIN);

  }

}

void MX_SPI1_Init(void)
{

  /* SPI1 parameter configuration*/
  hspi1.Instance = SPI1;
  hspi1.Init.Mode = SPI_MODE_MASTER;
  hspi1.Init.Direction = SPI_DIRECTION_2LINES;
  hspi1.Init.DataSize = SPI_DATASIZE_8BIT;
  hspi1.Init.CLKPolarity = SPI_POLARITY_LOW;
  hspi1.Init.CLKPhase = SPI_PHASE_1EDGE;
  hspi1.Init.NSS = SPI_NSS_SOFT;
  hspi1.Init.BaudRatePrescaler = SPI_BAUDRATEPRESCALER_8;
  hspi1.Init.FirstBit = SPI_FIRSTBIT_MSB;
  hspi1.Init.TIMode = SPI_TIMODE_DISABLE;
  hspi1.Init.CRCCalculation = SPI_CRCCALCULATION_DISABLE;

  if (HAL_SPI_Init(&hspi1) != HAL_OK)
  {
    Error_Handler();
  }
}


void HAL_SPI_MspInit(SPI_HandleTypeDef* hspi)
{
    if (hspi->Instance != SPI1) {
        return;
    }

    SPI_GPIO_CLK_ENABLE();
    __HAL_RCC_SPI1_CLK_ENABLE();

    GPIO_InitTypeDef GPIO_InitStruct = {0};
    GPIO_InitStruct.Pin = SPI_SCK_PIN | SPI_MISO_PIN | SPI_MOSI_PIN;
    GPIO_InitStruct.Mode = GPIO_MODE_AF_PP;
    GPIO_InitStruct.Pull = GPIO_NOPULL;
    GPIO_InitStruct.Speed = GPIO_SPEED_FREQ_HIGH;
    GPIO_InitStruct.Alternate = GPIO_AF0_SPI1;
    HAL_GPIO_Init(SPI_GPIO_PORT, &GPIO_InitStruct);

    GPIO_InitStruct.Pin = RADIO_CS_PIN ;
    GPIO_InitStruct.Mode = GPIO_MODE_OUTPUT_PP;
    GPIO_InitStruct.Pull = GPIO_NOPULL;
    GPIO_InitStruct.Speed = GPIO_SPEED_FREQ_HIGH;
    HAL_GPIO_Init(GPIOA, &GPIO_InitStruct);
    HAL_GPIO_WritePin(RADIO_CS_PORT, RADIO_CS_PIN, GPIO_PIN_SET);

}

/**
  * @brief SPI MSP De-Initialization
  * This function freeze the hardware resources used in this example
  * @param hspi: SPI handle pointer
  * @retval None
  */
void HAL_SPI_MspDeInit(SPI_HandleTypeDef* hspi)
{
  if(hspi->Instance==SPI1)
  {
    /* Peripheral clock disable */
    __HAL_RCC_SPI1_CLK_DISABLE();

    /**SPI1 GPIO Configuration
    PA5     ------> SPI1_SCK
    PA6     ------> SPI1_MISO
    PA7     ------> SPI1_MOSI
    */
    HAL_GPIO_DeInit(GPIOA, SPI_SCK_PIN|SPI_MISO_PIN|SPI_MOSI_PIN | RADIO_CS_PIN);

  }

}

void MX_GPIO_Init(void)
{
  GPIO_InitTypeDef GPIO_InitStruct = {0};
  /* GPIO Ports Clock Enable */
  __HAL_RCC_GPIOA_CLK_ENABLE();
  __HAL_RCC_GPIOB_CLK_ENABLE();

  /*Configure GPIO pin Output Level */
  HAL_GPIO_WritePin(GPIOA, RADIO_RESET_PIN|RADIO_RX_SW_PIN|RADIO_TX_SW_PIN, GPIO_PIN_RESET);

  /*Configure GPIO pin Output Level */
  HAL_GPIO_WritePin(GPIOB, GNSS_RESET_PIN, GPIO_PIN_RESET);

  /*Configure GPIO pins : LoRa_Reset_Pin LoRa_NSS_Pin LoRa_RX_Switch_Pin */
  GPIO_InitStruct.Pin = RADIO_RESET_PIN|RADIO_RX_SW_PIN|RADIO_TX_SW_PIN;
  GPIO_InitStruct.Mode = GPIO_MODE_OUTPUT_PP;
  GPIO_InitStruct.Pull = GPIO_NOPULL;
  GPIO_InitStruct.Speed = GPIO_SPEED_FREQ_LOW;
  HAL_GPIO_Init(GPIOA, &GPIO_InitStruct);

  /*Configure GPIO pins : LoRa_TX_Switch_Pin GNSS_RESET_Pin */
  GPIO_InitStruct.Pin = GNSS_RESET_PIN;
  GPIO_InitStruct.Mode = GPIO_MODE_OUTPUT_PP;
  GPIO_InitStruct.Pull = GPIO_NOPULL;
  GPIO_InitStruct.Speed = GPIO_SPEED_FREQ_LOW;
  HAL_GPIO_Init(GPIOB, &GPIO_InitStruct);

}
#endif // F0

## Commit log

2026-01-20 Circuit laid out
    I forgot github existed sorry, need to assign footprints and decide on pins to use on the MCU, then route the PCB
    [GNSS.kicad_sch, LoRa.kicad_sch, teachtaire.kicad_pcb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]
2026-01-24 Added values to components
    [GNSS.kicad_sch]
2026-01-29 Finished Schematic and Routed PCB
    [GNSS.kicad_sch, LoRa.kicad_sch, teachtaire.kicad_pcb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]
2026-01-30 minorest of changes
    [teachtaire.kicad_pcb, teachtaire.kicad_sch]
2026-02-10 Changes from Reddit review 1
    Changed connector, impedance matched the RF traces, changed board to square
    [GNSS.kicad_sch, teachtaire.kicad_pcb, teachtaire.kicad_sch]
2026-02-11 lots to be sorted
    [teachtaire.kicad_pcb]
2026-02-22 many fatal fuck-ups found
    [GNSS.kicad_sch, power.kicad_sch, teachtaire.kicad_pcb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]
2026-02-22 fixed the fuck-ups
    [GNSS.kicad_sch, power.kicad_sch, teachtaire.kicad_pcb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]
2026-02-23 power and main routing done, just need to set rf trace width
    [teachtaire.kicad_pcb, teachtaire.kicad_sch]
2026-02-23 good to go
    [teachtaire.kicad_pcb, teachtaire.kicad_sch]
2026-02-23 ddio pins
    [teachtaire.kicad_pcb, teachtaire.kicad_sch]
2026-02-23 ready for review the twost
    [teachtaire.kicad_pcb, teachtaire.kicad_sch]
2026-02-27 ready to go, nearly
    [teachtaire-B_Cu.gbr, teachtaire-B_Mask.gbr, teachtaire-B_Paste.gbr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]
2026-03-01 ready 2 order
    [GNSS.kicad_sch, power.kicad_sch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]
